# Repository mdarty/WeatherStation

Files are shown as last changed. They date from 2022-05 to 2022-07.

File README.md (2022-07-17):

# WeatherStation
ESP32 Weather Station
Weather_Station.jpegWeather_Station

## WARNING
This is my first C++ program so good luck haha.

## USE
Copy Example_settings.h to settings.h and fill in your info

## Dependincies
All are in the arduino libraries.
  * APRS-IS
  * ArduinoJson
  * driver/adc
  * ESP32Time
  * esp_system
  * LTR390
  * math
  * PubSubClient
  * SparkFunBME280
  * WiFi
  * Wire

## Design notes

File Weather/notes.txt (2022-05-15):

layout items:
* looks like you've got a bunch of individual ground traces left over from before you added zones for it 
* did you really want 1.0mm pitch headers for the right side?  those only leave 0.15mm between the pads, and JLC's capabilities say 0.2mm.
* I'd probably have done GND on one side and +3.3V on the other, so you can just drop vias down instead of snaking a 3.3V trace all the way across the board.
* internal acute angles are traditionally frowned-upon, but probably fine for now.  they used to catch the etchant and not completely get rinsed off but that's less of a problem now I think.
* holy crap the 1N5820 is a chonky diode

@darty
I think SMD is great, but if I'm going to solder it I want through pin. Always fun to solder an smd mount part with the shakes.

mokomull — Yesterday at 10:19 PM
get some solder paste and a hot air reflow station and it feels like cheating

Add gps for time Most look to be serial

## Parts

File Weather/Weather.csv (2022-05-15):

Reference | Quantity | Value | Footprint | JLCPCB | Part Number | Datasheet | MANUFACTURER | PARTREV
C1 | 1 | 4.7nF | Capacitor_SMD:C_1206_3216Metric_Pad1.33x1.80mm_HandSolder | C106073 |  | ~
C2 C3 C4 | 3 | 0.1 uF | Capacitor_SMD:C_1206_3216Metric_Pad1.33x1.80mm_HandSolder | C107181 |  | ~
C5 | 1 | 180uf/35V | Capacitor_THT:CP_Radial_D8.0mm_P3.50mm | https://www.mouser.com/ProductDetail/Panasonic/35SEK180M |  | ~
C6 | 1 | 470uf/35V | Capacitor_THT:CP_Radial_D10.0mm_P5.00mm | https://www.mouser.com/ProductDetail/Panasonic/EEH-AZS1V471B |  | ~
C7 | 1 | 105 | Capacitor_SMD:C_1206_3216Metric_Pad1.33x1.80mm_HandSolder | C1848 | CL31B105KBHNNNE | https://datasheet.lcsc.com/lcsc/1810271109_Samsung-Electro-Mechanics-CL31B105KBHNNNE_C1848.pdf | Samsung Electro-Mechanics
D1 D2 D3 | 3 | BAV99 | Package_TO_SOT_SMD:SOT-23 | C305472 |  | https://assets.nexperia.com/documents/data-sheet/BAV99_SER.pdf
D4 | 1 | 1N5820 | Diode_THT:D_DO-201AD_P15.24mm_Horizontal | https://www.mouser.com/ProductDetail/onsemi/1N5820G?qs=y2kkmE52mdMaZomtu%252BD%252BfQ%3D%3D |  | http://www.vishay.com/docs/88526/1n5820.pdf
J11 | 1 | 2.5 mm | darty_stuff:2.5mm_Stereo_Jack | https://www.mouser.com/ProductDetail/Kobiconn/161-7000-EX |  | https://www.mouser.com/datasheet/2/253/KC-300946-1177561.pdf
J2 J3 | 2 | RJ12 | Connector_RJ:RJ12_Amphenol_54601 | https://www.mouser.com/ProductDetail/Molex/42878-6216?qs=yYVs2tXBqMPaSjdPYoO9rg%3D%3D |  | ~
J5 | 1 | 3.5 mm | darty_stuff:3.5mm_Stereo_Jack | https://www.mouser.com/ProductDetail/Kobiconn/161-7400-EX?qs=D76ag%252Bk%252BuJhTaHNkgHRNDA%3D%3D |  | https://www.mouser.com/datasheet/2/253/KC-300830-1177500.pdf
L1 | 1 | 68uh/2A | darty_stuff:inductor_1004_SMD | C143968 | MWSA1004-680MT | https://datasheet.lcsc.com/szlcsc/Sunlord-MWSA1004-680MT_C143968.pdf
R1 | 1 | 33K | Resistor_SMD:R_1206_3216Metric_Pad1.30x1.75mm_HandSolder | C229931 |  | ~
R10 | 1 | 100K | Resistor_SMD:R_1206_3216Metric_Pad1.30x1.75mm_HandSolder | C118849 |  | ~
R12 R13 | 2 | 43k | Resistor_SMD:R_1206_3216Metric_Pad1.30x1.75mm_HandSolder | C352072 |  | ~
R2 R8 R11 R14 | 4 | 10K | Resistor_SMD:R_1206_3216Metric_Pad1.30x1.75mm_HandSolder | C118075 |  | ~
R3 | 1 | 3.3K | Resistor_SMD:R_1206_3216Metric_Pad1.30x1.75mm_HandSolder | C229599 |  | ~
R5 | 1 | 1K | Resistor_SMD:R_1206_3216Metric_Pad1.30x1.75mm_HandSolder | C102060 |  | ~
R9 | 1 | 22K | Resistor_SMD:R_1206_3216Metric_Pad1.30x1.75mm_HandSolder | C352116 |  | ~
U2 | 1 | CJ431 | Package_TO_SOT_SMD:SOT-89-3_Handsoldering | C8497
U3 | 1 | XL1509-5.0E1 | darty_stuff:SOIC-8_5x4 | C61063 | XL1509-5.0E1 | https://datasheet.lcsc.com/lcsc/1809050422_XLSEMI-XL1509-5.0E1_C61063.pdf | XLSEMI

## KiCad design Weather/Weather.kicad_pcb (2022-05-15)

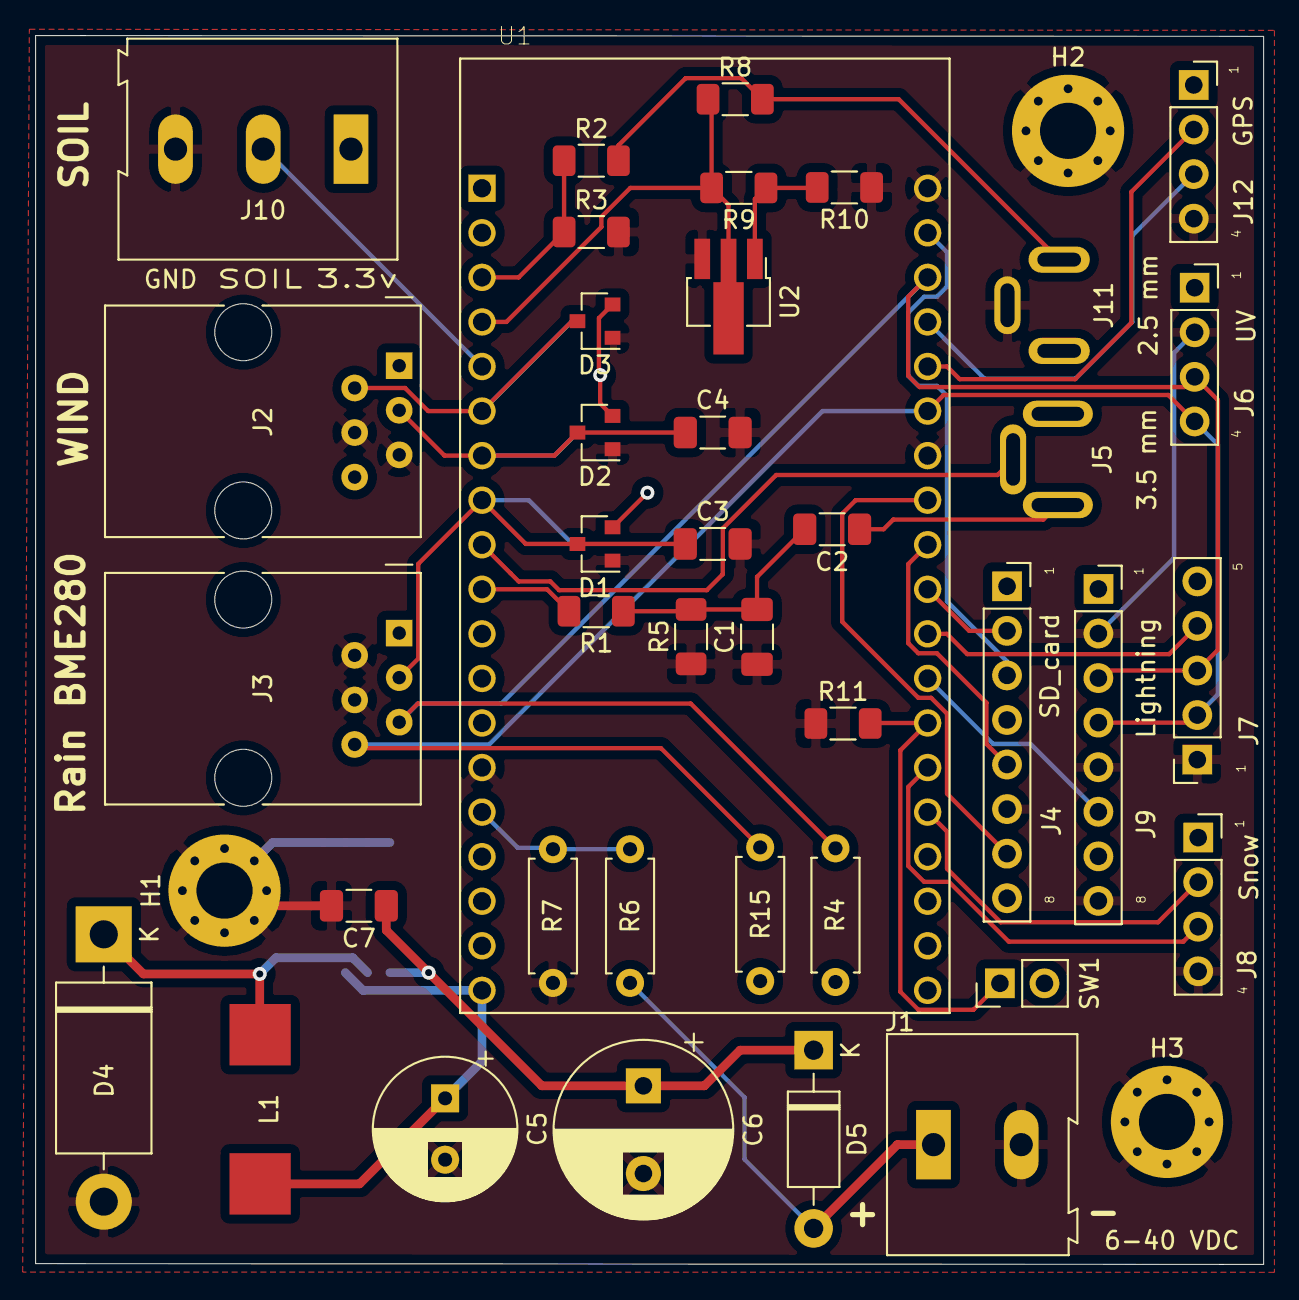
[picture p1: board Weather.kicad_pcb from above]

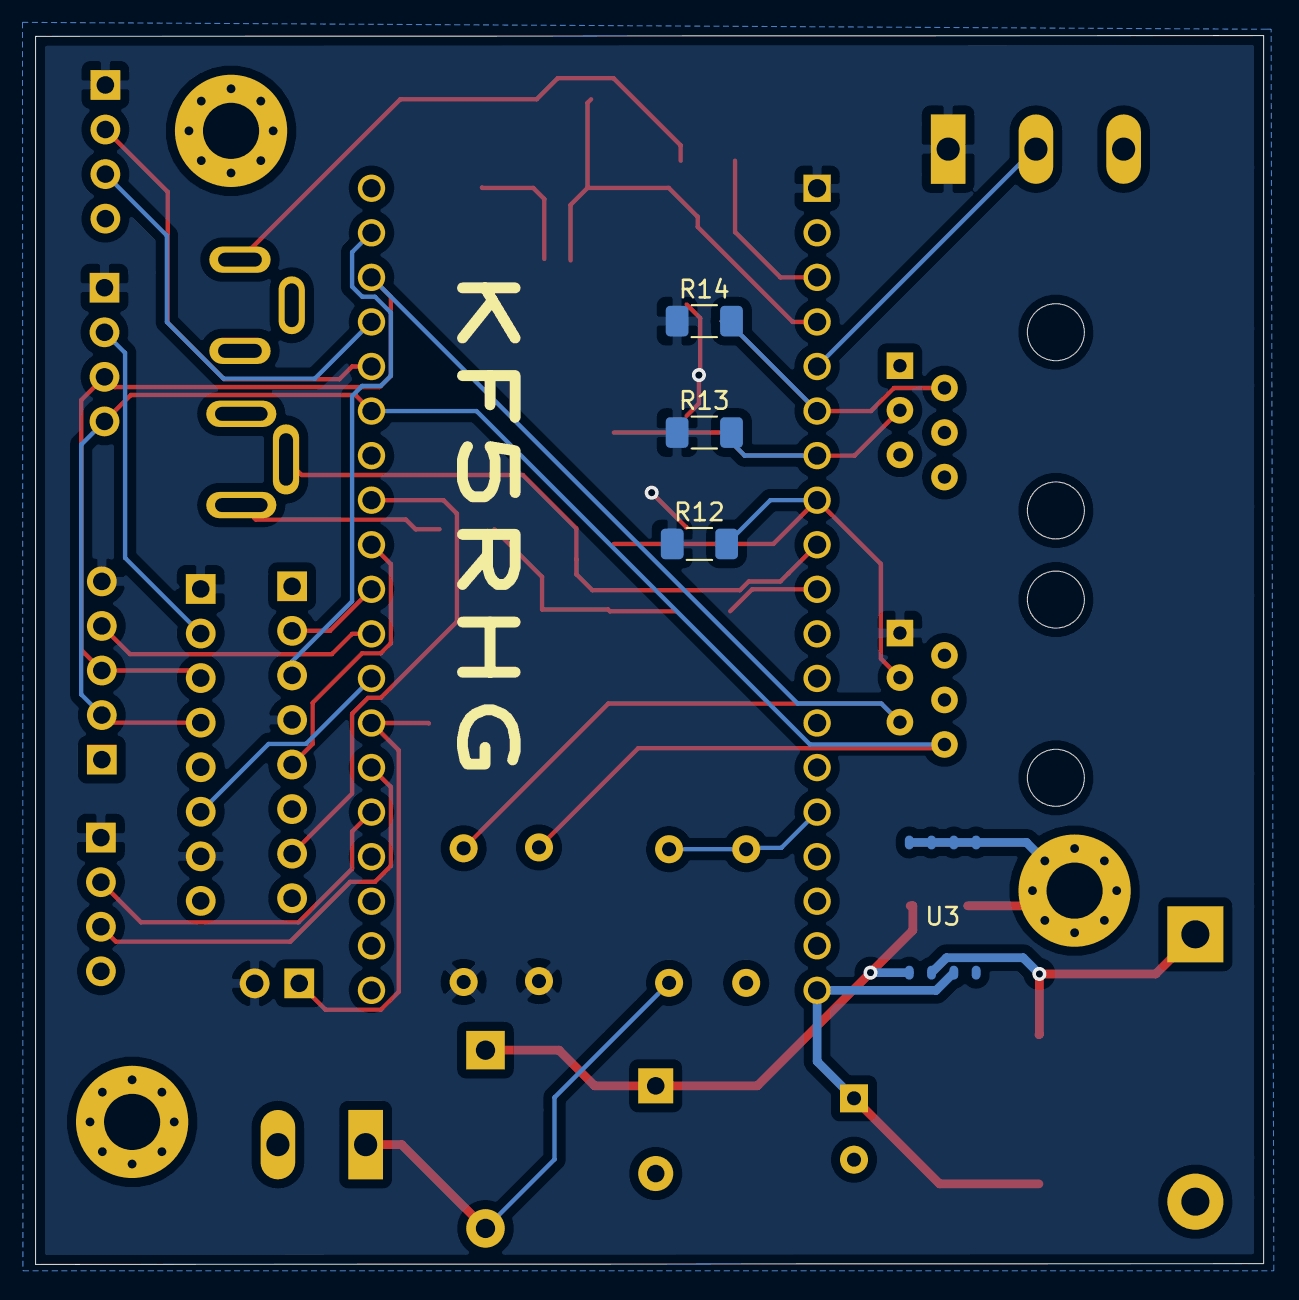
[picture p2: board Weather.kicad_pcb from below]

Board: 2 copper layers, 70.0 x 70.0 mm, 47 parts (4 on the bottom side), 32 nets.

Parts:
C1: 4.7nF; C_1206_3216Metric_Pad1.33x1.80mm_HandSolder
C2, C3, C4: 0.1 uF; C_1206_3216Metric_Pad1.33x1.80mm_HandSolder
C5: 180uf/35V; CP_Radial_D8.0mm_P3.50mm
C6: 470uf/35V; CP_Radial_D10.0mm_P5.00mm
C7: 105; C_1206_3216Metric_Pad1.33x1.80mm_HandSolder
D1, D2, D3: BAV99; SOT-23
D4: 1N5820; D_DO-201AD_P15.24mm_Horizontal
D5: 1N5819; D_DO-41_SOD81_P10.16mm_Horizontal
H1, H2: MountingHole_Pad; MountingHole_3.2mm_M3_Pad_Via
H3: MP; MountingHole_3.2mm_M3_Pad_Via
J1: 6-40 VDC; TerminalBlock_Altech_AK300-2_P5.00mm
J2: RJ12 - Wind; RJ12_Amphenol_54601
J3: RJ12 - Rain; RJ12_Amphenol_54601
J4: SD_card; PinSocket_1x08_P2.54mm_Vertical
J5: 3.5 mm; 3.5mm_Stereo_Jack
J6: UV; PinSocket_1x04_P2.54mm_Vertical
J7: RTC; PinSocket_1x05_P2.54mm_Vertical
J8: Snow; PinSocket_1x04_P2.54mm_Vertical
J9: Lightning; PinSocket_1x08_P2.54mm_Vertical
J10: Soil; TerminalBlock_Altech_AK300-3_P5.00mm
J11: 2.5 mm; 2.5mm_Stereo_Jack
J12: GPS; PinSocket_1x04_P2.54mm_Vertical
L1: 68uh/2A; inductor_1004_SMD
R1: 33K; R_1206_3216Metric_Pad1.30x1.75mm_HandSolder
R2, R8: 10K; R_1206_3216Metric_Pad1.30x1.75mm_HandSolder
R3: 3.3K; R_1206_3216Metric_Pad1.30x1.75mm_HandSolder
R4, R6, R7, R15: ??; R_Axial_DIN0207_L6.3mm_D2.5mm_P7.62mm_Horizontal
R5: 1K; R_1206_3216Metric_Pad1.30x1.75mm_HandSolder
R9: 22K; R_1206_3216Metric_Pad1.30x1.75mm_HandSolder
R10: 100K; R_1206_3216Metric_Pad1.30x1.75mm_HandSolder
R11, R14: 10k; R_1206_3216Metric_Pad1.30x1.75mm_HandSolder
R12, R13: 43k; R_1206_3216Metric_Pad1.30x1.75mm_HandSolder
SW1: SW_SPST; PinHeader_1x02_P2.54mm_Vertical
U1: ESP32-DEVKITC-32D; MODULE_ESP32-DEVKITC-32D
U2: CJ431; SOT-89-3_Handsoldering
U3: XL1509-5.0E1; SOIC-8_5x4

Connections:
3.3v: D1.2, D2.2, D3.2, J3.1, J4.4, J6.1, J7.5, J8.1, J9.1, J9.7, J10.1, J12.1, R4.1, R12.1, R13.1, R14.1, R15.1, SW1.2, U1.1
5v: C5.1, L1.1, U1.19, U3.3
ADC: R2.1, R3.1, U1.3
BAT: D5.2, J1.1, R6.1
B_spkr: J11.T, R2.2, R8.2
Chr: R6.2, R7.1, U1.15
DAC: R1.2, U1.10
Echo: J8.3, U1.33
GND: C1.1, C3.2, C4.2, C5.2, C6.2, C7.2, D1.1, D2.1, D3.1, D4.2, H1.1, H2.1, H3.1, J1.2, J2.4, J2.5, J3.2, J3.4, J4.6, J6.2, J7.1, J8.4, J9.2, J9.5, J9.8, J10.3, J11.S, J12.4, R3.2, R5.1, R7.2, R10.1, R11.1, U1.14, U1.20, U1.26, U2.3, U3.5, U3.6, U3.7, U3.8
IRQ: J9.6, U1.31
MFP: J7.4, U1.30
unnamed: C1.2, C2.2, R1.1, R5.2
unnamed: C6.1, C7.1, D5.1, U3.1
unnamed: D4.1, L1.2, U3.2
unnamed: R9.1, R10.2, U2.1
PTT: J5.S, U1.9
RX: J12.2, U1.24
Rain: C3.1, D1.3, J3.3, R12.2, U1.8
SCL: J3.5, J6.3, J7.3, J9.3, R4.2, U1.22
SDA: J3.6, J6.4, J7.2, J9.4, R15.2, U1.25
SD_CS: J4.2, U1.29
SD_safe: R11.2, SW1.1, U1.32
SOIL: J10.2, U1.5
SPI_CIPO: J4.7, U1.27
SPI_COPI: J4.3, U1.21
SPI_SCK: J4.5, U1.28
TX: J12.3, U1.23
Trig: J8.2, U1.34
Wdir: D3.3, J2.2, R14.2, U1.6
Wspd: C4.1, D2.3, J2.3, R13.2, U1.7
b_mic: C2.1, J5.R
trigger: R8.1, R9.2, U1.4, U2.2

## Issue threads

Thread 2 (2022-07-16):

MOSFET stuck on

mdarty, 2022-07-16:
Even though it says it isn't charging the MOSFET is conducting.

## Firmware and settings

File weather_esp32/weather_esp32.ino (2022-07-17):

#include "settings.h"

//Libraries
#include <WiFi.h>
#include "driver/adc.h"
#include "esp_system.h" //This inclusion configures the peripherals in the ESP system.

//NTP
#include <ESP32Time.h>

//Variables
bool dataReady = false;
bool collect_dots = false;
byte batteryLevel = 0;

ESP32Time rtc;
struct tm timeinfo;
bool ModemSleep = true;

//timers
volatile unsigned long five_seconds = millis();
volatile unsigned long five_minutes = millis();
volatile unsigned long ntp_timer = millis();
volatile unsigned long aprs_timer = millis();
volatile unsigned long five_delay = millis();
volatile unsigned long bat_delay = millis();

#include <ADS1115_WE.h>
#include <Wire.h>
ADS1115_WE adc = ADS1115_WE(ADC_ADDRESS);

//My stuff
#include "Rain.h"
#include "Wind.h"
WindMath Wind;
RainMath Rain;
#include "Battery.h"

#include "helpers.h"

#ifdef MQTT
#include "MQTT.h"
#endif

#ifdef APRS
#include "APRS.h"
#endif

#include "Sleep.h"

void setup() {
  // put your setup code here, to run once:
  #ifdef DEBUG
    Serial.begin(115200);
    Serial.println("Setup");
  #endif
  sensor_config();
  wifi_connect();
  /*---------set with NTP---------------*/
  configTime(gmtOffset_sec, daylightOffset_sec, ntpServer);
  if (getLocalTime(&timeinfo)) {
    rtc.setTimeStruct(timeinfo);
  }
  rain_setup();
  wind_setup();
  //setModemSleep();//"AB1CDE-10>APRS,AB1CDE:=1234.12N/12345.12E-QTH von AB1CDE"
  #ifdef MQTT
    MQTT_config();
  #endif
  #ifdef APRS
    APRS_send(); //FW0690>APRS,TCPIP*:!DDMM.hhN/DDDMM.hhW$comments
  #endif
  bat_setup();
  bat_charge();
}

void loop() {
  if (millis() - five_seconds > sample_time) {
    //Collect wind sample every 5 seconds, this is required for gusts
    if (collect_dots) {
      Serial.print(".");
    } else {
      Serial.print("Collect Wind Sample ");
      collect_dots = true;
    }
    Serial.print(".");

    Wind.collect_sample();
    five_seconds = millis();
  } else if (millis() - five_minutes > report_time) {
    //Read everything and calculated needed things
    collect_dots = false;
    Serial.println(" ");
    Serial.println("I2C Samples");
    I2C_read();
    Serial.print("Rain Samples");
    Rain.calc(rtc.getMinute(), rtc.getHour(), rtc.getMonth(), rtc.getDay(), rtc.getDayofWeek());
    Serial.println(" ");
    Serial.println("Wind Samples");
    Wind.calc();
    Serial.println("Done Calc Samples");
    five_minutes = millis();
    dataReady = true;
  } else if ( dataReady && (millis() - aprs_timer > report_time) && (millis() - five_delay > 5000) ) {
#ifdef SLEEP
    enableWiFi();
#endif
    if (millis() - ntp_timer > ntp_time) {
      if (getLocalTime(&timeinfo)) {
        //record time difference?
        rtc.setTimeStruct(timeinfo);
      }
      #ifdef MQTT
        MQTT_config();
      #endif
    }
    collect_dots = false;
    Serial.println(" ");
    Serial.println("Report Sample");
    w_data ws = load_data();
    aprs_timer = millis();
    dataReady = false;
#ifdef MQTT
    MQTT_send_data(ws);
#endif
#ifdef APRS
    APRS_send_data(ws);
#endif
#ifdef SLEEP
    disableWiFi();
#endif
  } else if (millis() - bat_delay > 5000) {
    bat_delay = millis();
    bat_charge();
  }
}

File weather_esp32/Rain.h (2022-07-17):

#ifndef RAIN_H_
#define RAIN_H_

unsigned int rain_count = 0;
unsigned int rain_count_mid = 0;
unsigned long r_mid_change = 0;
volatile unsigned long rain_last_micros;
const unsigned int _24_len = 86400000/report_time + 0.5; //86,400,000 milliseconds in 24 hours, sampled every 5 minutes
const unsigned int _hour_len = 3600000/report_time + 0.5; //3,600,000 milliseconds in an hour, sampled every 5 minutes
//#define MID_WAIT 3600000 // don't even look for an hour

void rain_inc() {
  if((long)(micros() - rain_last_micros) >= DEBOUNCING_TIME) {
    rain_count++;
    rain_count_mid++;
    rain_last_micros = micros();
  }
}

void rain_setup() {
  pinMode(RAIN_PIN, INPUT_PULLUP);
  attachInterrupt(digitalPinToInterrupt(RAIN_PIN), rain_inc, FALLING);
}

//Keep everything as count until publishing.
class RainMath {
  // bucket_size = 0.2794mm 0.011inches
  // Rain should be in hundredths of an inch
  private:
    unsigned int _24_array[_24_len] = {0};
    unsigned int _24_index = 0;
    const float _bucket = 1.1; //hundreths of an inch
    volatile unsigned long _last_24;
    unsigned int _hour_array[_hour_len] = {0};
    volatile unsigned long _last_hour;
    byte _hour_index = 0;

    float readChannel(ADS1115_MUX channel) {
      float voltage = 0.0;
      adc.setCompareChannels(channel);
      adc.startSingleMeasurement();
      while(adc.isBusy()){}
      voltage = adc.getResult_mV(); // alternative: getResult_mV for Millivolt
      return voltage;
    }
    
    bool IsDST(byte month, byte day, byte dow) {
      //Return DaylightSavingsTime is true or false
      if (month < 3 || month > 11) {
        return false;
      }
      if (month > 3 && month < 11) {
        return true;
      }
      int previousSunday = day - dow;
      if ((month == 3) && (previousSunday >= 8)) {
        return true;
      }
      return false;
    }


    void _r_mid (int min, int hr, int month, int day, int dow) {
      //      char tmid[7] = "050000z"
      //      char fmid[7] = "060000z"
      //Checks daylight savings time and when local time is midnight it resets counter to zero and restarts timer.
      if (min == 0) {
        if (((hr == 5) && (IsDST(month, day, dow))) || ((hr == 6) && (!IsDST(month, day, dow)))) {
          rain_count_mid = 0;
          r_mid_changed = millis();
        }
      }
      r_mid = (_bucket * rain_count_mid) + 0.5;
    }

    int _24_next() {
      //circular index for 24 hours
      _24_index++;
      if (_24_index > _24_len) {
        _24_index = 0;
      }
      return _24_index;
    }

    void _r_24_sum(){
      //Last rain fall for 24 hours
      unsigned int rain_24 = 0;
      _24_array[_24_next()] = rain_count;
      
      // byte isn't large enough
      for (unsigned int i = 0; i < _24_len; i++) {
        rain_24 += _24_array[i];
      }
      r_24_sum = rain_24 * _bucket + 0.5; // 0.5 + rounds properly when turning to int
    }

    int _hour_next() {
      //circular index for 24 hours
      _hour_index++;
      if (_hour_index > _hour_len) {
        _hour_index = 0;
      }
      return _hour_index;
    }

    void _r_hour_sum(){
      //Last rain fall for 24 hours
      unsigned int rain_hour = 0;
      _hour_array[_hour_next()] = rain_count;
      
      // byte isn't large enough
      for (unsigned int i = 0; i < _hour_len; i++) {
        rain_hour += _hour_array[i];
      }
      r_hour_sum = rain_hour * _bucket + 0.5; // 0.5 + rounds properly when turning to int
    }

    void _soil_moisture(){
      float V = readChannel(SOIL_PIN);
      const unsigned int H = 800;
      const unsigned int L = 460;
      if (V > H) {
        soil_moisture = 0;
      } else if (V < L) {
        soil_moisture = 100;
      } else {
        soil_moisture = (H-L) / (H-L) * 100.0;
      }
    }

        
  public:
    volatile unsigned long r_mid_changed;
    unsigned int r_hour_sum;
    unsigned int r_24_sum;
    unsigned int r_mid;
    unsigned int soil_moisture;

    void calc(int min, int hr, int month, int day, int dow) {
      //take sample
      _r_hour_sum();
      
      Serial.println("Rain: Midnight");
      
      _r_mid (min, hr, month, day, dow);
      
      Serial.println("Rain: 24");
      
      _r_24_sum();
      rain_count = 0;

      _soil_moisture();
    }
};


#endif

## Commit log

2022-05-15 Adding inital Arduino Code and KiCad
    [Weather-B_Cu.gbr, Weather-B_Fab.gbr, Weather-B_Mask.gbr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]
2022-05-15 Reorganized stuff and updated Wind Directions
    [Weather Station.ods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]
2022-05-16 Fixed Serial Nightmare and corrected spelling
    [weather_esp32.ino]
2022-05-18 Configured hassio and Updated time and fixed wind and rain bugs
    [Rain.h, Wind.h, weather_esp32.ino]
2022-05-26 Added ADS1115, fixed wdir, soil, worked on hassio, but it still doesn't perform discovery properly
    [Weather.kicad_sch]
2022-06-20 Solar Panel Battery Charger
2022-06-20 Missed some files and corrected a resistor setup
    [Audio.kicad_sch, Program.kicad_sch, Sensors.kicad_sch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]
2022-07-17 Fixed rounding and reporting errors
    [Rain.h, Wind.h, weather_esp32.ino]
